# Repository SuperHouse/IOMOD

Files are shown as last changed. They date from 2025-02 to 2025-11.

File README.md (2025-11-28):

# IOMOD Multi-Purpose I/O Module

*Copyright 2025 SuperHouse Automation Pty Ltd  
[www.superhouse.tv]()*

IOMOD is a mechanical and electrical convention for creating pluggable 
I/O modules for use in test systems and other projects.

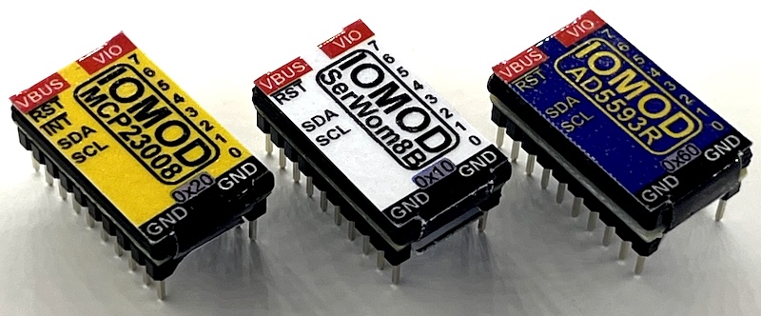
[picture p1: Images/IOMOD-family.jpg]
IOMOD family


The module pinout allows for either I2C or SPI connections to modules, 
and up to 8 I/O pins per module. Modules can also optionally support two 
power domains so that data connections to the host can be at a different 
voltage to connections to the target device.

4 reference implementations have been created so far:

 * AD5593R (I2C)
 * MCP23008 (I2C)
 * MCP23S08 (SPI)
 * Serial Wombat 8B (I2C)

These reference implementations have been designed "upside down", so 
that when they are assembled the parts will be underneath the module. 
This allows the top of the module to be totally flat except for the tops 
of the header pins and their solder joints.

Note: The format is DIP, but it's NOT on a 0.1" grid! That means you
can't plug it into a breadboard. The format is 2mm pitch metric DIP with
10mm row spacing center-to-center. An adapter module design is also 
provided to allow easy use in a breadboard.

Originally developed for the [Testomatic PCB test jig system](https://github.com/superhouse/testomatic).
The Testomatic chassis includes sockets for 7 IOMODs, allowing different 
modules to be installed based on the specific requirements of the test 
plan for the Device Under Test.

## IOMOD Pinout

IOMOD designs are not required to implement all signals. Typically an I2C-based 
module will leave the SPI-related pins unconnected, and vice versa. Modules 
may also omit signals such as the active-low interrupt output or 
the reset pin, and they don't need to implement all 8 GPIO signals.

For example, a module designed specifically for a high-speed SPI 
single-channel high-precision ADC may implement a single GPIO and leave 
the rest unconnected. This is perfectly valid if it suits your use-case.

Modules may also choose to fully isolate the power domains, with a 
floating GND on the I/O side split from the signal GND on the control side. 
The reference designs included here tie both GND pins together as a 
common reference, but if you want to design a module with full galvanic 
isolation you can choose to keep the GND pins separated from each other.

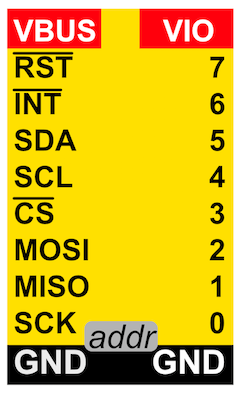
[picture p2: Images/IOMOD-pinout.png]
IOMOD Pinout


| Pin | Name  | Use |
|---|---|---|
| 1 | VBUS  | Voltage for control interface |
| 2 | !RST  | Reset input to module (active low) |
| 3 | !INT  | Interrupt output from module (active low) |
| 4 | SDA | I2C data |
| 5 | SCL | I2C clock |
| 6 | !CS | SPI chip select (active low) |
| 7 | MOSI  | SPI MOSI |
| 8 | MISO  | SPI MISO |
| 9 | SCK | SPI clock |
| 10 | LGND  | Logic ground |
| 11 | IOGND | I/O ground |
| 12-19 | IOx | I/O pins |
| 20 | VIO | Voltage for I/O pins |

## IOMOD Mechanical Dimensions

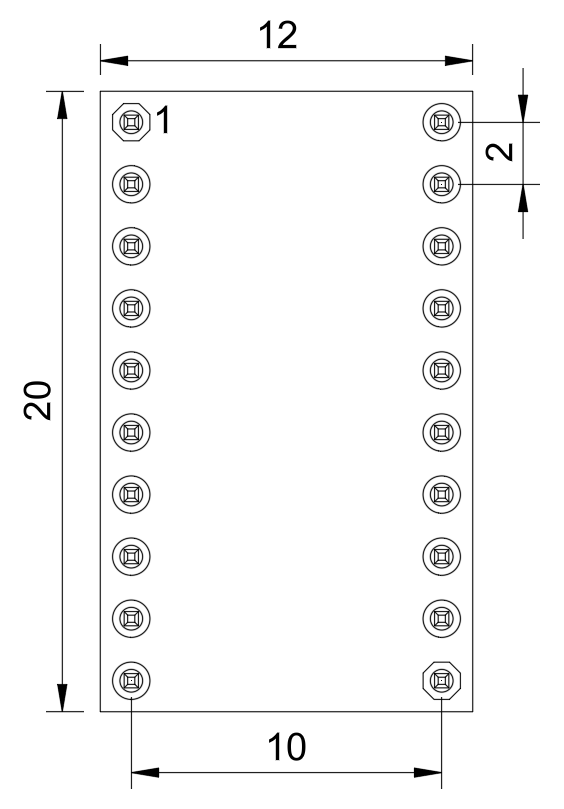
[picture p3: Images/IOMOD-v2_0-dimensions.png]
IO Mod Dimensions


## 2mm-to-0.1" Adapter

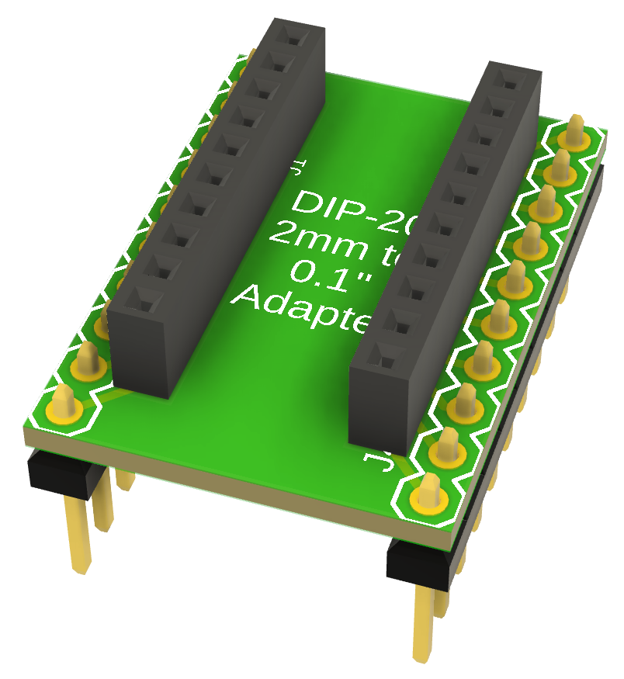
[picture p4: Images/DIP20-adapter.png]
2mm to 0.1" breakout


## Labelling

A 3D-printed cap design is included that can be glued onto the top of 
the module to give it a large flat area for labels. A dab of Loctite 
Extreme Gel or other suitable glue will hold it in place. It has recesses 
to allow it to sit down over the ends of the header pins.

Labels for the reference designs are included as an Affinity document 
and an A4 PDF. The labels have tabs that wrap underneath the module 
to hold the label firmly in place.

## Insertion / Removal Tool

A 3D-printed tool design is included to make it easier to insert and 
remove modules from a carrier board. Testomatic has 7 IOMODs mounted 
close together so they're tricky to get out with your fingers.

The tool uses a compliant-mechanism hinge. The hinge is a little fragile 
but seems to work OK when printed in PLA. It may be more durable in PETG.

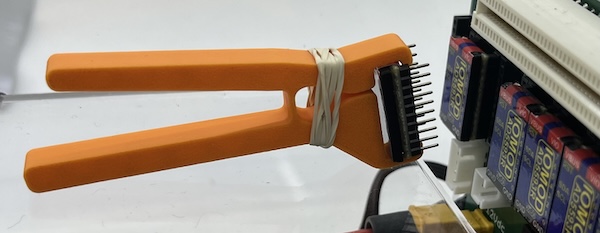
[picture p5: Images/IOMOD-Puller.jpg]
IOMOD Puller


## IOMOD-AD5593R

This variant is designed to be a generic I/O module that provides basic
features to cover typical use cases where high ADC precision, etc is
not required. It's very flexible because it can handle both analog and 
digital input and output with true analog output via the DAC, but unfortunately 
the AD5593R chips are quite expensive.

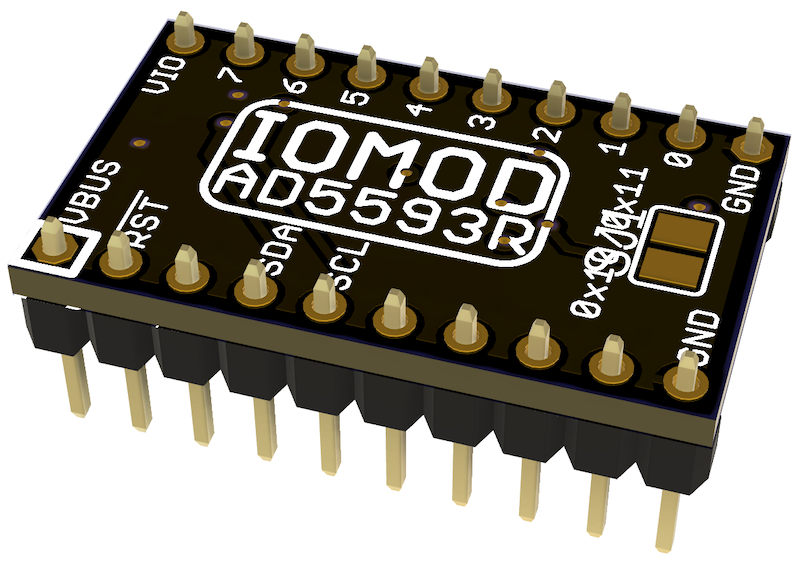
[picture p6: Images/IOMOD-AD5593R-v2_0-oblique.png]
IOMOD-AD5593R


**Features**

 * AD5593R I/O expander.
 * I2C interface.
 * 8 I/O pins.
 * 3.3V or 5V control interface.
 * 3.3V or 5V I/O interface.
 * Every pin can be individually configured.
 * Digital I/O on every pin.
 * 12-bit ADC on every pin.
 * 12-bit DAC on every pin.

For use with Arduino, see Rob Tillaart's excellent library at [github.com/RobTillaart/AD5593R](https://github.com/RobTillaart/AD5593R)

## IOMOD-MCP23008

This variant is based on the extremely popular MCP23008 I2C I/O expander 
chip, which means it has excellent driver support. However, it is only 
capable of digital input and output. It doesn't support analog I/O at all. 
This makes it less flexible than the AD5593R module, but probably simpler 
to set up in terms of software support. It's also significantly cheaper. 

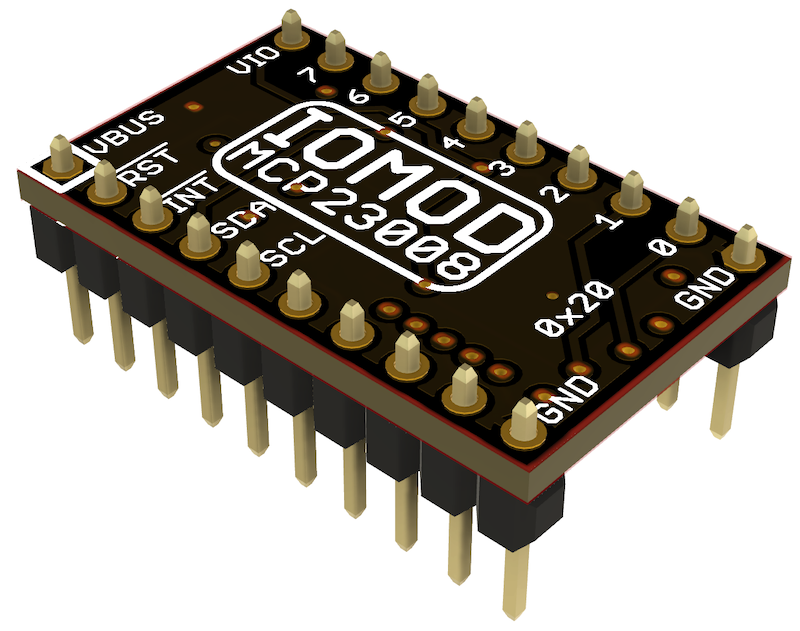
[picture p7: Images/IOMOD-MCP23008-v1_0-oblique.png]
IOMOD-MCP23008


**Features**

 * MCP23008 I/O expander.
 * I2C interface.
 * 8 I/O pins.
 * 3.3V or 5V control interface.
 * 3.3V or 5V I/O interface.
 * Digital I/O on every pin.

## IOMOD-MCP23S08

This variant has the same features as the MCP23008 module, except that it 
uses SPI for communication with the host. It was implemented mostly to 
validate that the IOMOD header format is also useful for SPI-based modules.

**Features**

 * MCP23S08 I/O expander.
 * SPI interface.
 * 8 I/O pins.
 * 3.3V or 5V control interface.
 * 3.3V or 5V I/O interface.
 * Digital I/O on every pin.

## IOMOD-SW8B

This variant is based on 
[SerialWombat from Broadwell Consulting](https://www.serialwombat.com/), 
which is a project to create an extremely flexible I/O expander using 
readily available MCUs. This IOMOD is based on the CH32V003 MCU, the same 
as used on the [SerialWombat 8B](https://www.kickstarter.com/projects/bwci/serial-wombat-8b-i2c-i-o-boards-big-features-small-money).

Because SerialWombat firmware allows advanced functionality to be 
offloaded to the I/O expander, it can be configured by the host and then 
left to handle its own tasks such as driving PWM, reading encoder 
signals, etc.

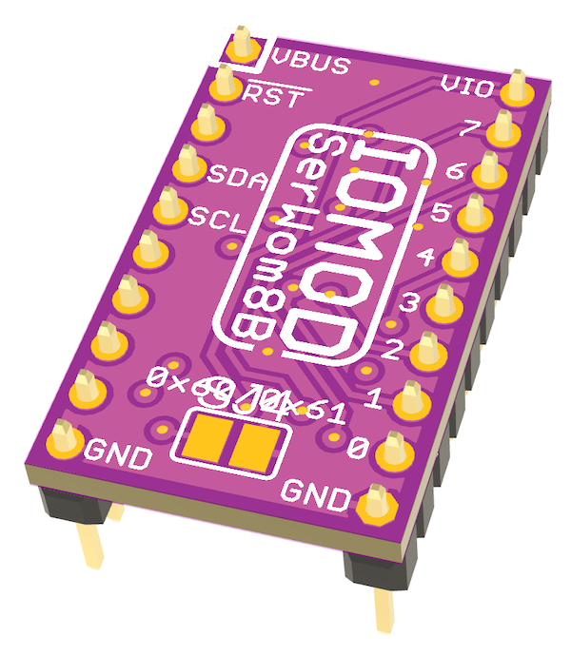
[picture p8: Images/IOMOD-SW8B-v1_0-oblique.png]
IOMOD-SW8B


More information to come.

INSTALLATION
------------
Schematics and PCBs were created in Fusion360 and exported as EAGLE format,
which can be imported back into Fusion360 or various other packages including KiCAD.

CREDITS
-------
Designed by Jonathan Oxer jon@oxer.com.au

DISTRIBUTION
------------
The specific terms of distribution of this project are governed by the
license referenced below.

LICENSE
-------
Licensed under the TAPR Open Hardware License (www.tapr.org/OHL).
The "license" folder within this repository also contains a copy of
this license in plain text format.

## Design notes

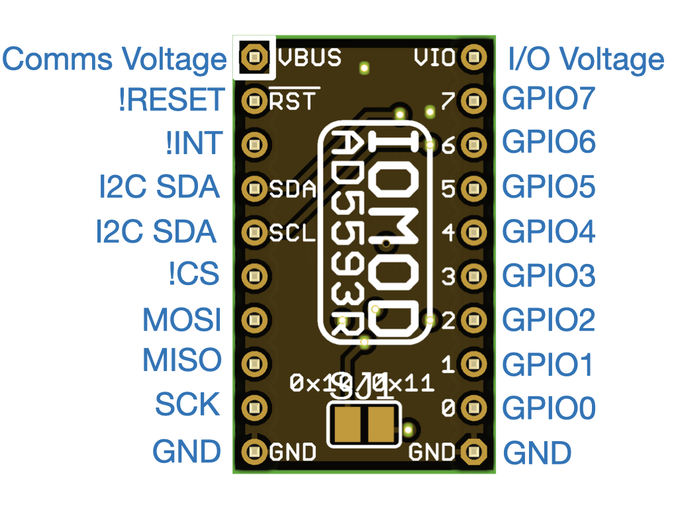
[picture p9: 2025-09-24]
Images/IOMOD-v2_0-pinout.jpeg

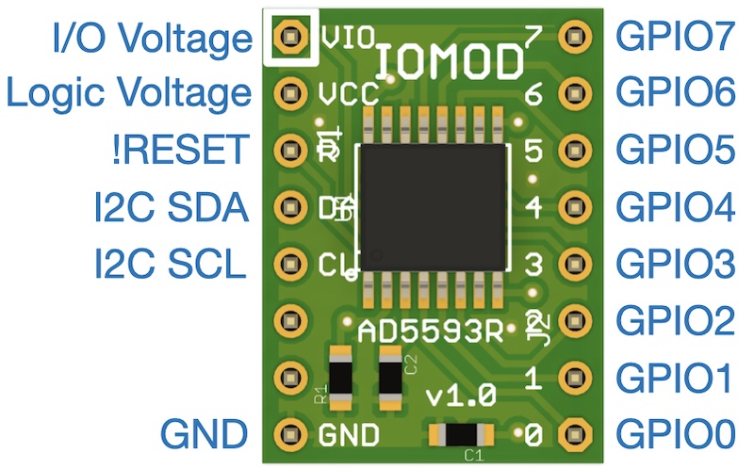
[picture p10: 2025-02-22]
Images/IOMOD-v1_0-pinout.jpeg

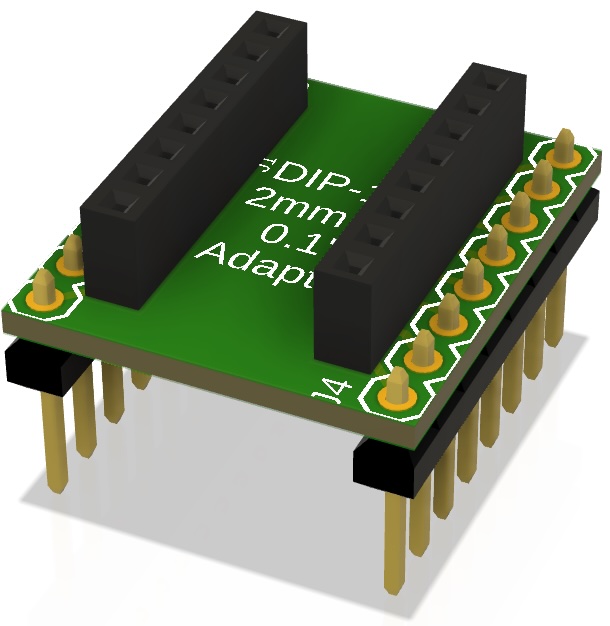
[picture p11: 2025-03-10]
Images/DIP-adapter.jpg

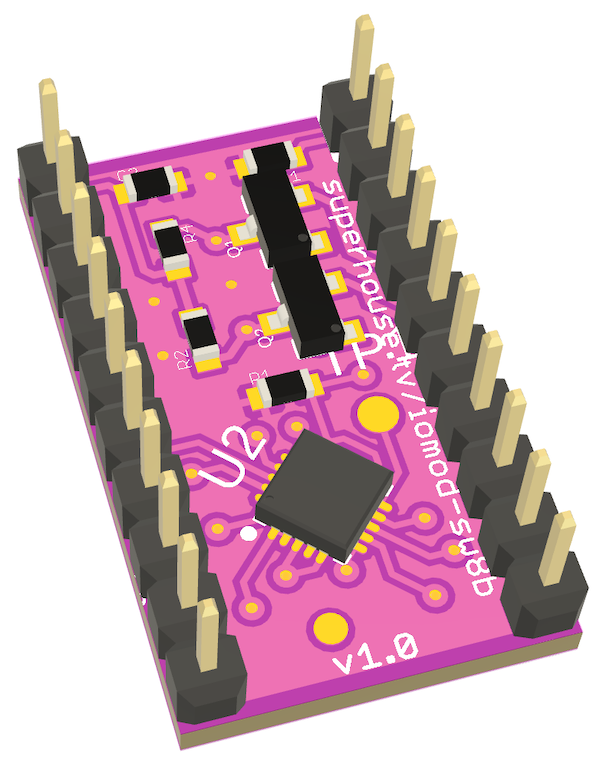
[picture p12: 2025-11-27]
Images/IOMOD-SW8B-v1_0-bottom.png

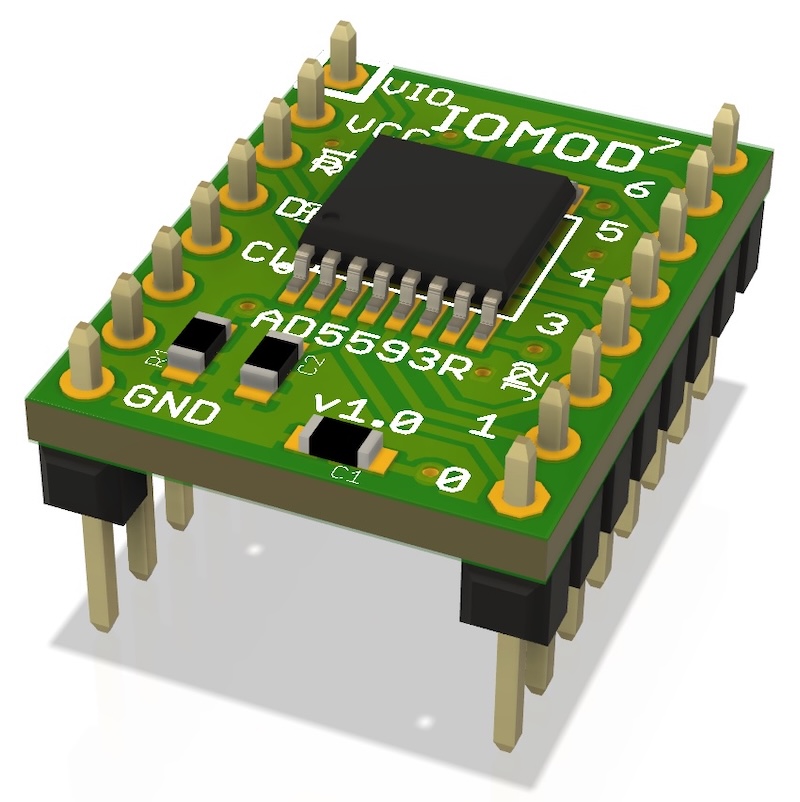
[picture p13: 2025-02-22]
Images/IOMOD-v1_0-oblique.jpeg

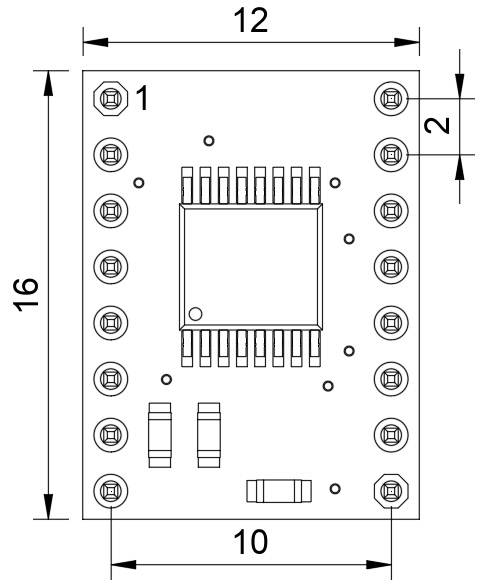
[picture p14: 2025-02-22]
Images/IOMOD-v1_0-dimensions.jpeg

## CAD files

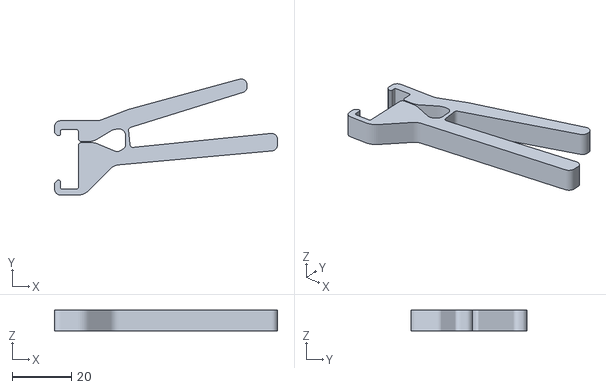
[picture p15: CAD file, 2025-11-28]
IOMOD-Puller.stl
75.0 x 39.0 x 7.00

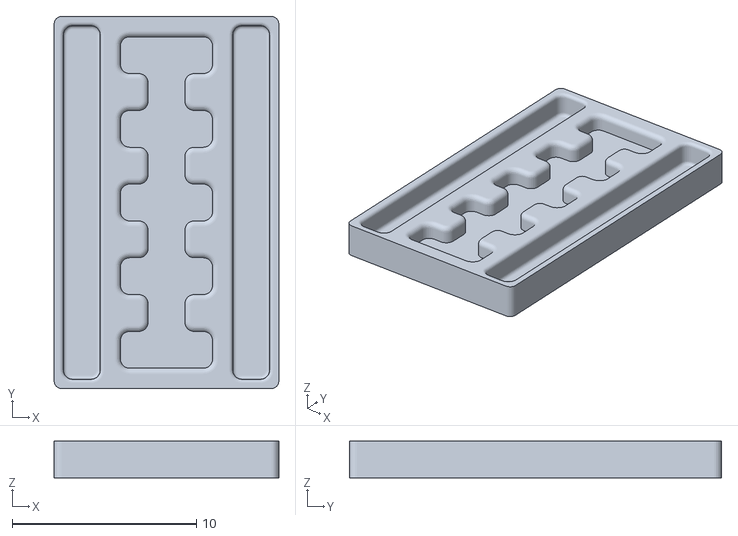
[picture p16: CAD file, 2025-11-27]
IOMOD-Cap.stl
12.2 x 20.2 x 2.00

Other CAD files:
DIP20-adapter/DIP20-2-2.54.f3z
IOMOD-AD5593R/IOMOD-AD5593R-v2_0.f3z
IOMOD-Cap.f3d
IOMOD-MCP23008/IOMOD-MCP23008-v1_0.f3z
IOMOD-Puller.f3d
IOMOD-SW8B/IOMOD-SW8B-v1_0.f3z

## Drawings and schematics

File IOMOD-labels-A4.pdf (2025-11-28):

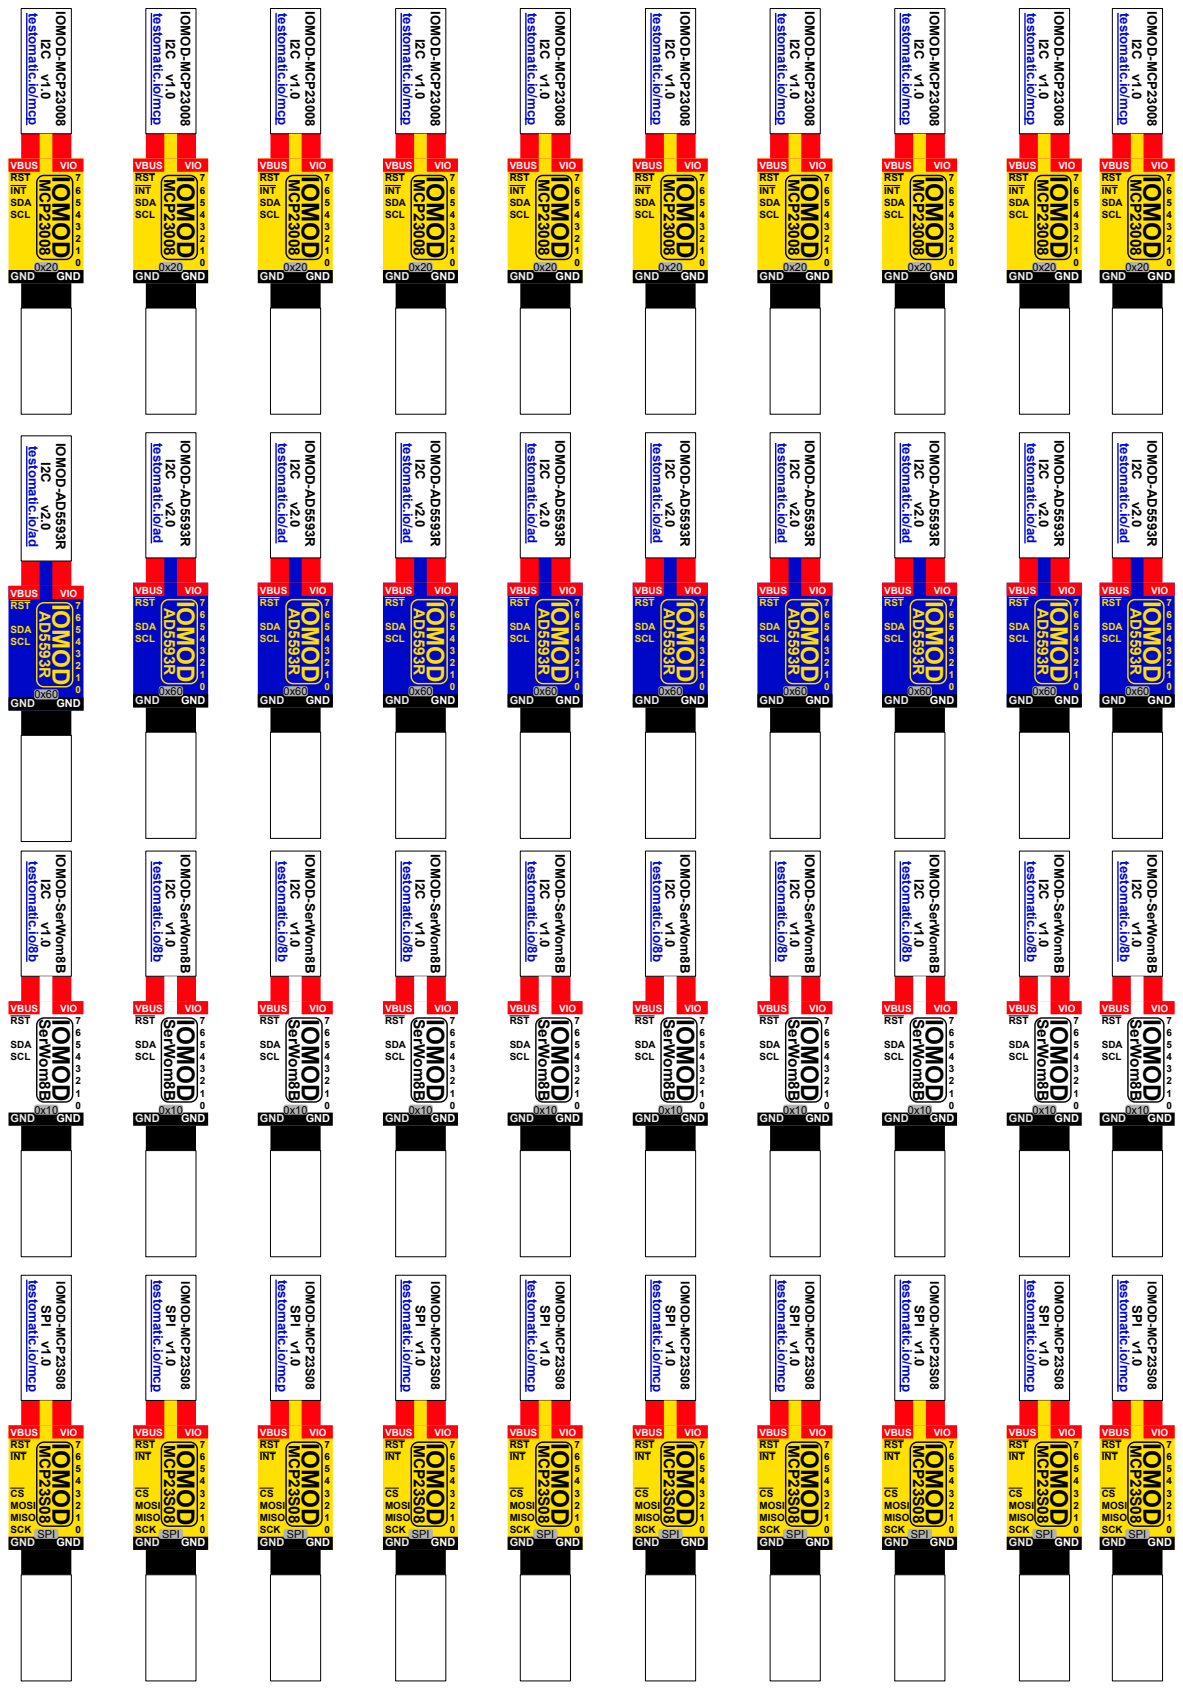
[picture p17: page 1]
VBUS RST; SDA SCL; GND; VIO . 7 6 5 4 3 2 1 0 GND; IOMOD; IOMOD-AD5593R; SerWom8B; testomatic.io/8b; IOMOD-SerWom8B; VBUS RST INT SDA SCL; MCP23008; IOMOD-MCP23008; IOMOD-AD5593R I2C v2.0 0x10; I2C v1.0 SPI; VBUS RST INT; CS MOSI MISO SCK GND; MCP23S08; IOMOD-MCP23S08; SPI v1.0; SPI

testomatic.io/mcp

testomatic.io/ad

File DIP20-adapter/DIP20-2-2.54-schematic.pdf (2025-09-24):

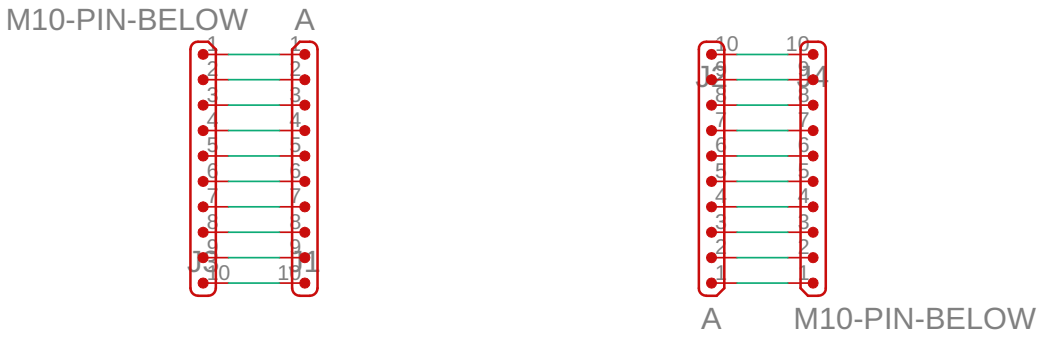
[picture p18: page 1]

(C)2025 SuperHouse Automation Pty Ltd

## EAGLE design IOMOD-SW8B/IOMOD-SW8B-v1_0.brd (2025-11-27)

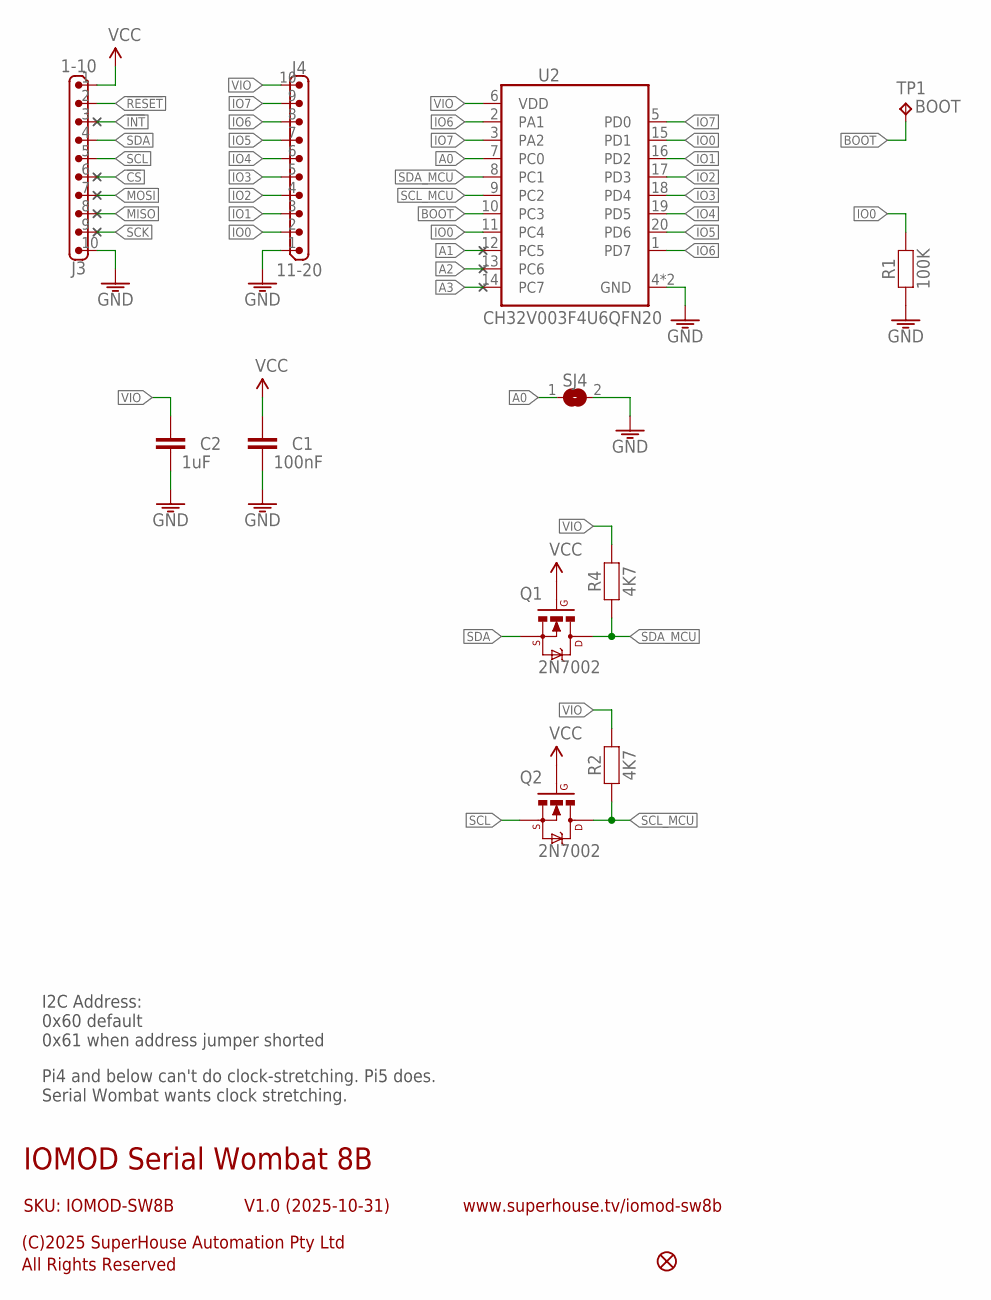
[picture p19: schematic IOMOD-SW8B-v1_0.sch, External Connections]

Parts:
C1: 100nF; C0603
C2: 1uF; C0603
FID1: FIDUCIAL1X2.5; FIDUCIAL-1X2.5
J3: 1-10; 1X10-2.00-P-ABOVE
J4: 11-20; 1X10-2.00-P-ABOVE
Q1, Q2: 2N7002; SOT23-3
R1: 100K; R0603
R2, R4: 4K7; R0603
SJ4: SJ-NORMAL; SJ
TP1: BOOT; B1,27
U2: CH32V003F4U6QFN20; QFN-20

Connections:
!CS: J3.6
!INT: J3.3
!RESET: J3.2
A0: SJ4.1, U2.7 (PC0)
A1: U2.12 (PC5)
A2: U2.13 (PC6)
A3: U2.14 (PC7)
BOOT: TP1.TP, U2.10 (PC3)
GND: C1.2, C2.2, J3.10, J4.1, R1.1, SJ4.2, U2.4 (GND), U2.21 (GND)
IO0: J4.2, R1.2, U2.11 (PC4), U2.15 (PD1)
IO1: J4.3, U2.16 (PD2)
IO2: J4.4, U2.17 (PD3)
IO3: J4.5, U2.18 (PD4)
IO4: J4.6, U2.19 (PD5)
IO5: J4.7, U2.20 (PD6)
IO6: J4.8, U2.1 (PD7), U2.2 (PA1)
IO7: J4.9, U2.3 (PA2), U2.5 (PD0)
MISO: J3.8
MOSI: J3.7
SCK: J3.9
SCL: J3.5, Q2.2 (S)
SCL_MCU: Q2.3 (D), R2.1, U2.9 (PC2)
SDA: J3.4, Q1.2 (S)
SDA_MCU: Q1.3 (D), R4.1, U2.8 (PC1)
VCC: C1.1, J3.1, Q1.1 (G), Q2.1 (G)
VIO: C2.1, J4.10, R2.2, R4.2, U2.6 (VDD)

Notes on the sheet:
IOMOD Serial Wombat 8B
V1.0 (2025-10-31)
SKU: IOMOD-SW8B
(C)2025 SuperHouse Automation Pty Ltd
All Rights Reserved
www.superhouse.tv/iomod-sw8b
I2C Address: 0x60 default 0x61 when address jumper shorted
Pi4 and below can't do clock-stretching. Pi5 does. Serial Wombat wants clock stretching.

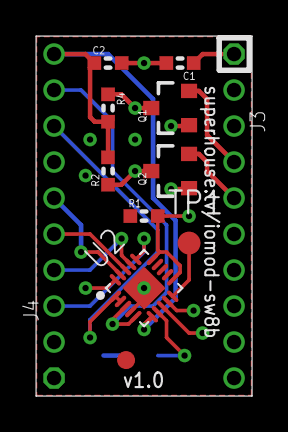
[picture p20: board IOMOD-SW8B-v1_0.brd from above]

Board: 4 copper layers, 12.0 x 20.0 mm, 13 parts (1 on the bottom side), 17 nets.

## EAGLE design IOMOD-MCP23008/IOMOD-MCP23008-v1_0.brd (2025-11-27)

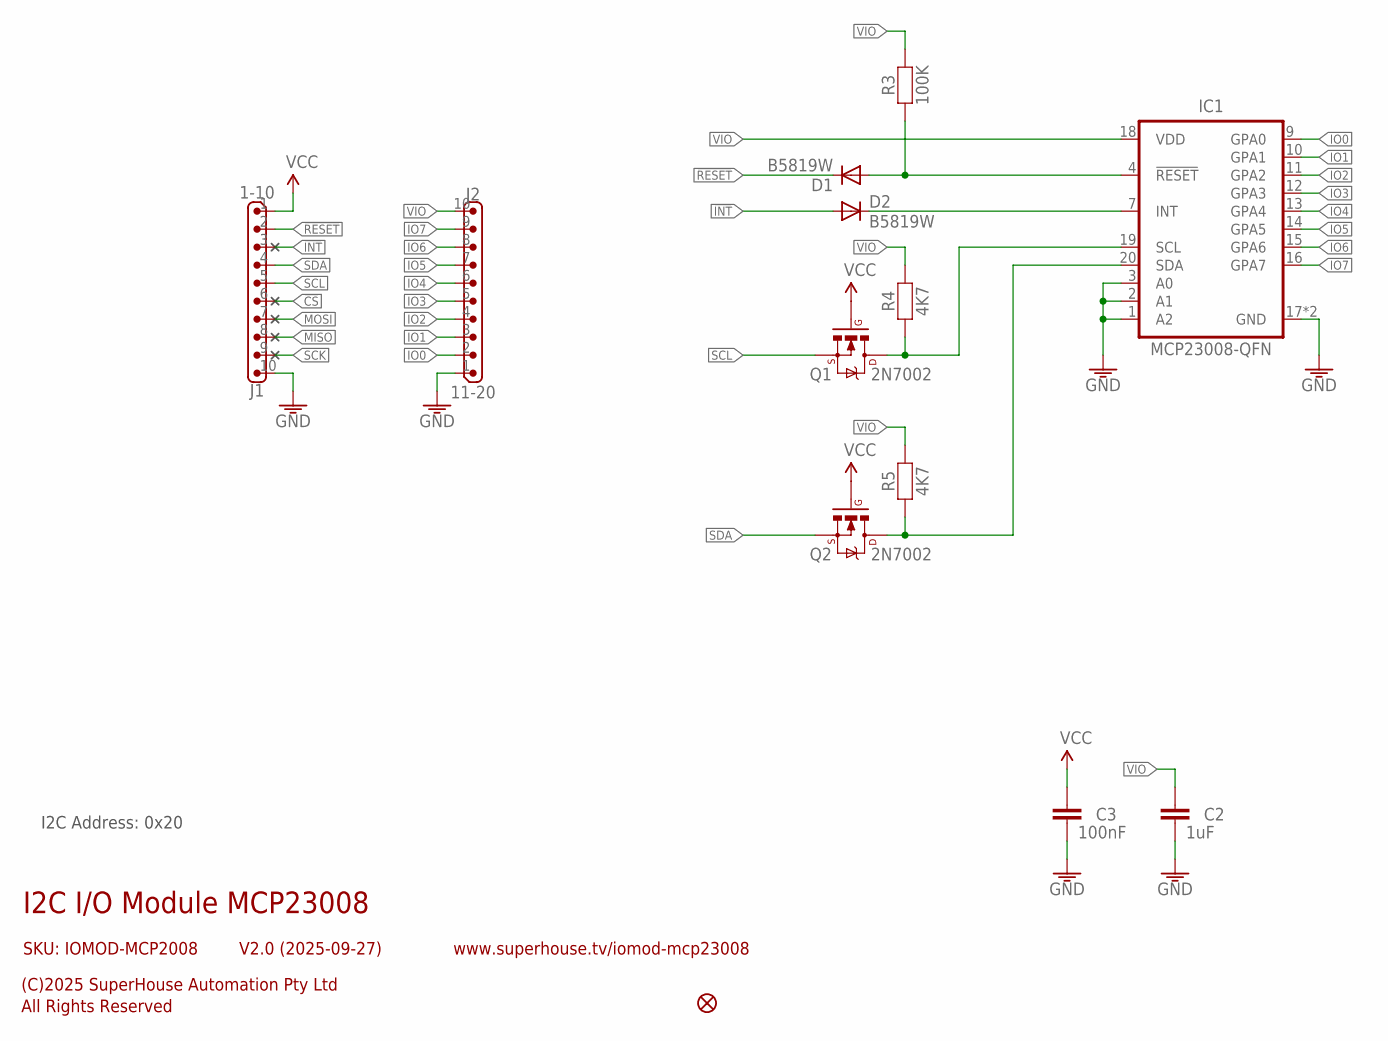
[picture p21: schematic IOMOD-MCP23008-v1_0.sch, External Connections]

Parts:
C2: 1uF; C0603
C3: 100nF; C0603
D1, D2: B5819W; SOD-123
FID1: FIDUCIAL1X2; FIDUCIAL-1X2
IC1: MCP23008-QFN; QFN-20
J1: 1-10; 1X10-2.00-P-ABOVE
J2: 11-20; 1X10-2.00-P-ABOVE
Q1, Q2: 2N7002; SOT23-3
R3: 100K; R0603
R4, R5: 4K7; R0603

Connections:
!CS: J1.6
!INT: D2.2 (A), J1.3
!RESET: D1.1 (C), J1.2
GND: C2.2, C3.2, IC1.1 (A2), IC1.2 (A1), IC1.3 (A0), IC1.17 (GND), IC1.TGND (GND), J1.10, J2.1
IO0: IC1.9 (GPA0), J2.2
IO1: IC1.10 (GPA1), J2.3
IO2: IC1.11 (GPA2), J2.4
IO3: IC1.12 (GPA3), J2.5
IO4: IC1.13 (GPA4), J2.6
IO5: IC1.14 (GPA5), J2.7
IO6: IC1.15 (GPA6), J2.8
IO7: IC1.16 (GPA7), J2.9
MISO: J1.8
MOSI: J1.7
unnamed: IC1.20 (SDA), Q2.3 (D), R5.1
unnamed: IC1.19 (SCL), Q1.3 (D), R4.1
unnamed: D2.1 (C), IC1.7 (INT)
unnamed: D1.2 (A), IC1.4 (!RESET), R3.1
SCK: J1.9
SCL: J1.5, Q1.2 (S)
SDA: J1.4, Q2.2 (S)
VCC: C3.1, J1.1, Q1.1 (G), Q2.1 (G)
VIO: C2.1, IC1.18 (VDD), J2.10, R3.2, R4.2, R5.2

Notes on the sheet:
I2C I/O Module MCP23008
V2.0 (2025-09-27)
SKU: IOMOD-MCP2008
(C)2025 SuperHouse Automation Pty Ltd
All Rights Reserved
www.superhouse.tv/iomod-mcp23008
I2C Address: 0x20

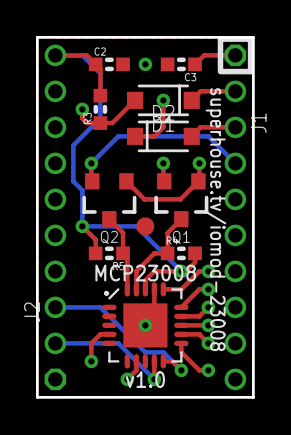
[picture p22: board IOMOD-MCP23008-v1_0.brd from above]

Board: 4 copper layers, 12.0 x 20.0 mm, 13 parts (0 on the bottom side), 19 nets.

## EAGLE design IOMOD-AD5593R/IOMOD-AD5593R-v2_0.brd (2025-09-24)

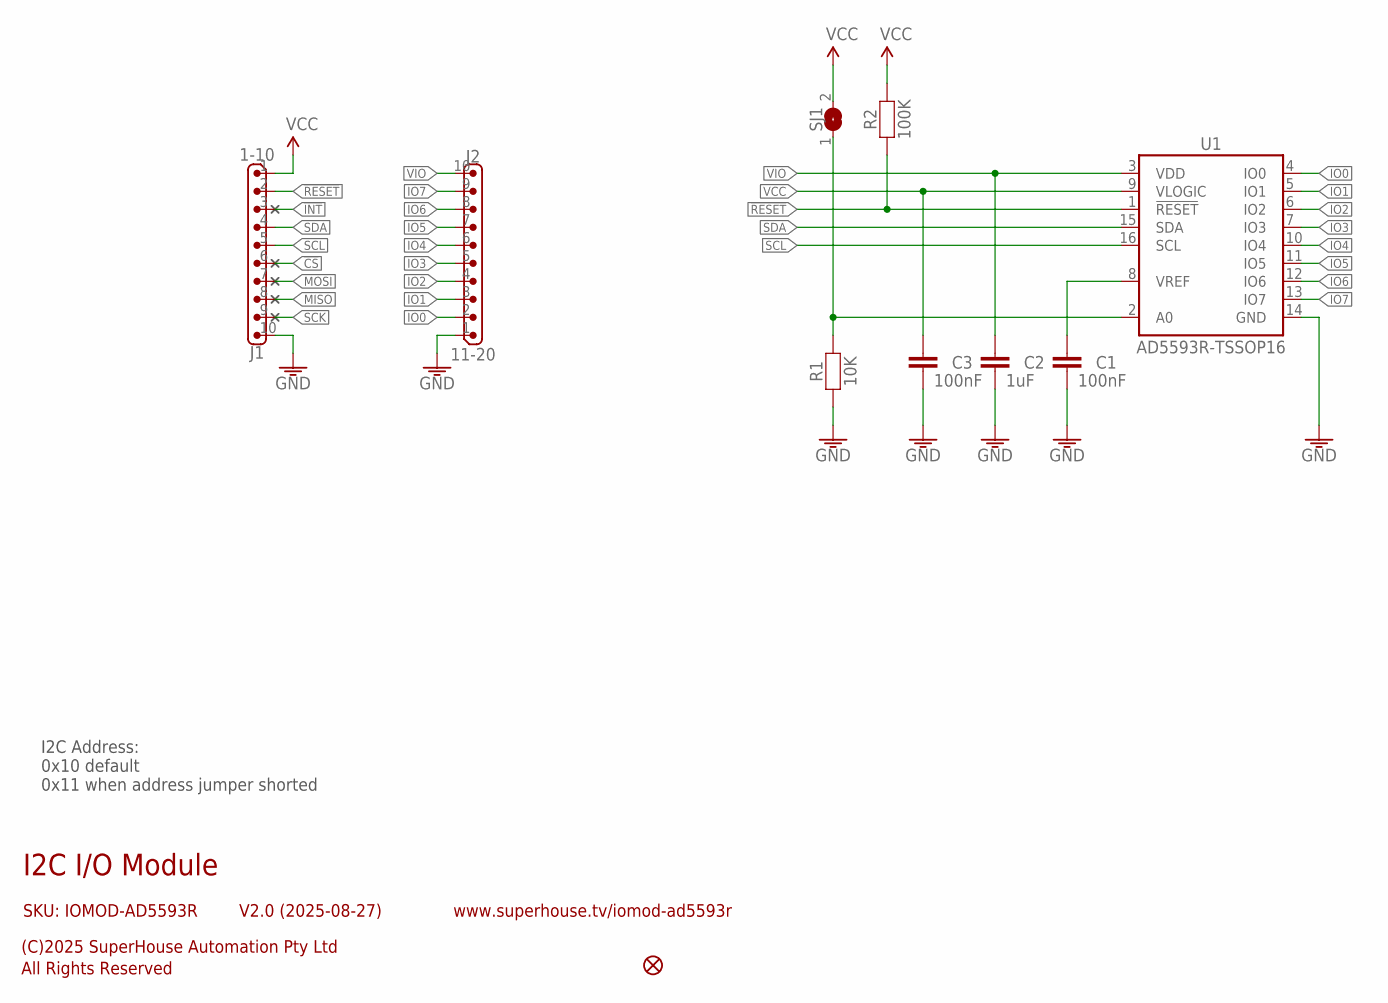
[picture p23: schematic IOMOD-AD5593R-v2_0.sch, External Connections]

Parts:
C1, C3: 100nF; C0603
C2: 1uF; C0603
FID1: FIDUCIAL1X2.5; FIDUCIAL-1X2.5
J1: 1-10; 1X10-2.00-P-ABOVE
J2: 11-20; 1X10-2.00-P-ABOVE
R1: 10K; R0603
R2: 100K; R0603
SJ1: SJ-NORMAL; SJ
U1: AD5593R-TSSOP16; TSSOP16

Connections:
!CS: J1.6
!INT: J1.3
!RESET: J1.2, R2.1, U1.1 (!RESET)
GND: C1.2, C2.2, C3.2, J1.10, J2.1, R1.1, U1.14 (GND)
IO0: J2.2, U1.4 (IO0)
IO1: J2.3, U1.5 (IO1)
IO2: J2.4, U1.6 (IO2)
IO3: J2.5, U1.7 (IO3)
IO4: J2.6, U1.10 (IO4)
IO5: J2.7, U1.11 (IO5)
IO6: J2.8, U1.12 (IO6)
IO7: J2.9, U1.13 (IO7)
MISO: J1.8
MOSI: J1.7
unnamed: R1.2, SJ1.1, U1.2 (A0)
unnamed: C1.1, U1.8 (VREF)
SCK: J1.9
SCL: J1.5, U1.16 (SCL)
SDA: J1.4, U1.15 (SDA)
VCC: C3.1, J1.1, R2.2, SJ1.2, U1.9 (VLOGIC)
VIO: C2.1, J2.10, U1.3 (VDD)

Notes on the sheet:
I2C I/O Module
V2.0 (2025-08-27)
SKU: IOMOD-AD5593R
(C)2025 SuperHouse Automation Pty Ltd
All Rights Reserved
www.superhouse.tv/iomod-ad5593r
I2C Address: 0x10 default 0x11 when address jumper shorted

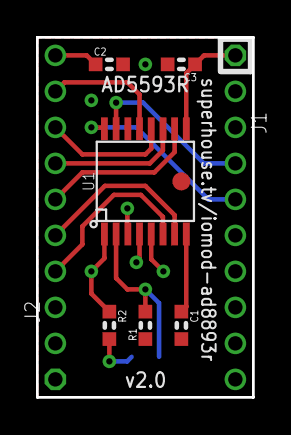
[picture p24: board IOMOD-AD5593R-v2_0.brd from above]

Board: 4 copper layers, 12.0 x 20.0 mm, 10 parts (1 on the bottom side), 16 nets.

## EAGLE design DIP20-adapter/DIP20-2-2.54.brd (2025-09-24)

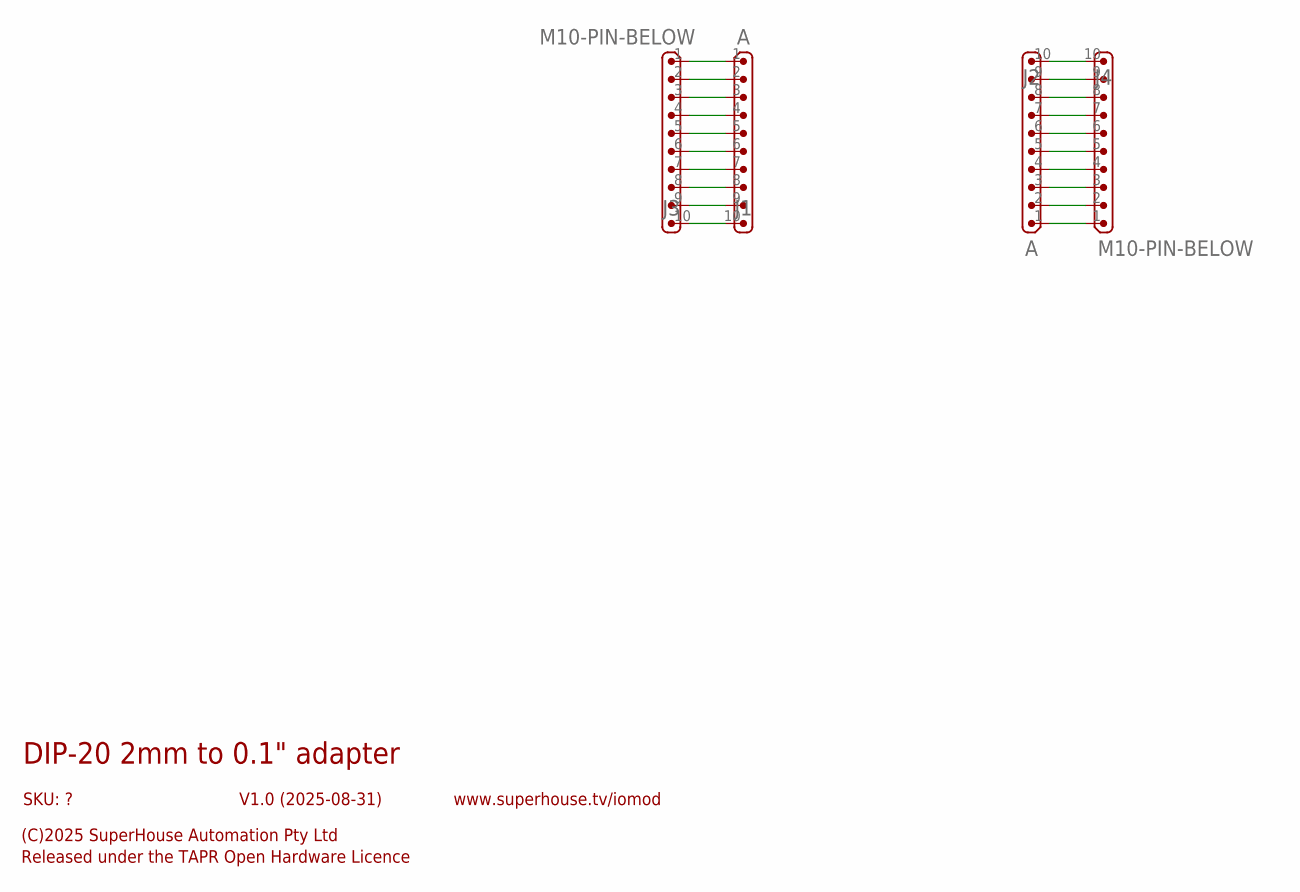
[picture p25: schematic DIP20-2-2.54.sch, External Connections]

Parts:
J1, J2: A; 1X10-2.00-S
J3, J4: M10-PIN-BELOW; 1X10-P-BELOW

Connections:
unnamed: J1.1, J3.1
unnamed: J1.2, J3.2
unnamed: J1.3, J3.3
unnamed: J1.4, J3.4
unnamed: J1.5, J3.5
unnamed: J1.6, J3.6
unnamed: J1.7, J3.7
unnamed: J1.8, J3.8
unnamed: J2.1, J4.1
unnamed: J2.2, J4.2
unnamed: J2.3, J4.3
unnamed: J2.4, J4.4
unnamed: J2.5, J4.5
unnamed: J2.6, J4.6
unnamed: J2.7, J4.7
unnamed: J2.8, J4.8
unnamed: J1.9, J3.9
unnamed: J1.10, J3.10
unnamed: J2.9, J4.9
unnamed: J2.10, J4.10

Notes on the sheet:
DIP-20 2mm to 0.1" adapter
V1.0 (2025-08-31)
SKU: ?
(C)2025 SuperHouse Automation Pty Ltd
Released under the TAPR Open Hardware Licence
www.superhouse.tv/iomod

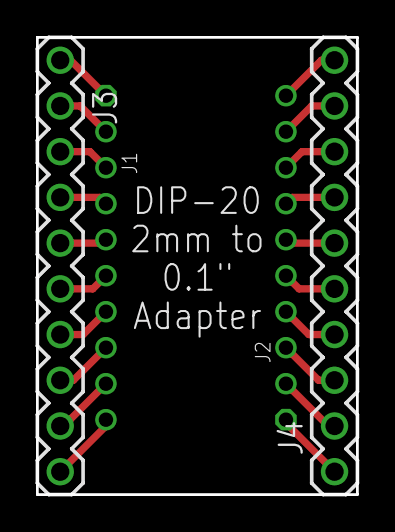
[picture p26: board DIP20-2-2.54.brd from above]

Board: 2 copper layers, 17.8 x 25.4 mm, 4 parts (0 on the bottom side), 20 nets.

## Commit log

2025-02-22 Initial import of project
    [IOMOD-v1_0.brd, IOMOD-v1_0.sch]
2025-02-22 Added Fusion360 archive version of design files.
    [IOMOD-v1_0.f3z]
2025-03-10 Added PDF of schematic.
2025-03-10 Added design for 2mm-to-0.1 DIP adapter
    [DIP16-2-2.54.brd, DIP16-2-2.54.sch]
2025-09-24 v2.0 release with major pinout change.
    [DIP20-2-2.54.brd, DIP20-2-2.54.f3z, DIP20-2-2.54.sch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]
2025-10-27 Added link to Rob's Arduino library
2025-11-27 Started rearranging files
    [DIP16-2-2.54.brd, DIP16-2-2.54.sch, DIP20-2-2.54.brd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]
2025-11-27 File rearrangement
    [DIP16-2-2.54.brd, DIP16-2-2.54.sch]
2025-11-27 Added files for MCP23008 and SW8B versions
    [IOMOD-MCP23008-v1_0.brd, IOMOD-MCP23008-v1_0.f3z, IOMOD-MCP23008-v1_0.sch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]
2025-11-27 Added 3D-printed caps
    [IOMOD-Cap.f3d, IOMOD-Cap.stl]
2025-11-28 Added pic of assembled modules with caps and labels
2025-11-28 Added printable labels
2025-11-28 Added design files for module puller tool
    [IOMOD-Puller.f3d, IOMOD-Puller.stl]
